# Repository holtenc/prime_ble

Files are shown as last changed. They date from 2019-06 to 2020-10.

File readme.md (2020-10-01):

This is a simple Bluetooth experiment I took on, just for grins. 

It utilizes an adafruit NRF51822 module and an Atmega32u4 MCU. Keyboard firmware is QMK

The portion of the schematic concerning the NRF module is based on the Adafruit Feather 32u4 Bluefruit LE schematic. 

A previous error in the PCB has been corrected by a contributor, but it has not been tested. 

These files are presented as-is for personal projects. They were created/uploaded in a time that I was ignorant of creating Kicad projects that were easily sharable so most likely you will get errors with schematic symbols and/or PCB footprints.

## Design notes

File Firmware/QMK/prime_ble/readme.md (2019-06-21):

# Prime_BLE

![Prime_BLE]()

An ergonomic bluetooth 45% keyboard with a macro/numpad added to the left side. 

Keyboard Maintainer: [Holtenc](https://github.com/holtenc/)  
Hardware Supported: Prime_ble PCB, ATMega32u4, NRF51822 
Hardware Availability: Prototype

Make example for this keyboard (after setting up your build environment):

    make handwired/prime_ble:default

See the [build environment setup](https://docs.qmk.fm/#/getting_started_build_tools) and the [make instructions](https://docs.qmk.fm/#/getting_started_make_guide) for more information. Brand new to QMK? Start with our [Complete Newbs Guide](https://docs.qmk.fm/#/newbs).

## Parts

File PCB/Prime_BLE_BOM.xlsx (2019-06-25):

Designator | Package | Quantity | Designation | Cost each | Total
D1 | IN-S124BR_LED | 1 |  | $0.30 | $0.30
D2 | IN-S124BR_LED | 1 |  | $0.30 | $0.30
CHG1 | IN-S124BR_LED | 1 |  | $0.30 | $0.30
D66,D67 | IN-S124BR_LED | 2 |  | $0.30 | $0.60
D3,D5,D6,D7,D8,D9,D10,D11,D12,D13,D14,D15,D16,D17,D18,D19,D20,D21,D22,D23,D24,D25,D26,D27,D28,D29,D30,D31,D32,D33,D34,D35,D36,D37,D38,D39,D40,D41,D42,D43,D44,D45,D46,D47,D48,D49,D50,D51,D52,D53,D54,D55,D56,D57,D58,D59,D60,D61,D62,D63,D64,D65 | D_SOD-123 | 62 |  | $0.10 | $6.20
SW4 | EG1213 | 1 | SW_SPDT | $0.65 | $0.65
C3 | 0603 | 1 | 470pF | $0.06 | $0.06
U4 | TQFP-44_10x10mm_P0.8mm | 1 | ATmega32U4-AU | $4.20 | $4.20
SW3,SW2,SW1 | TL3342F160 | 3 | SW_PUSH | $0.64 | $1.92
X2 | 2X05_1.27MM_BOX_POSTS | 1 | JTAG-CORTEXBOXPOSTS | $1.50 | $1.50
U1 | BLE_MODULE_RAYTAC_MDBT40 | 1 | MBT40 (adafruit 4076) | $7.50 | $7.50
X1 | JSTPH2 | 1 | S2B-PH-SM4-TB(LF)(SN) | $0.60 | $0.60
C1,C4 | 0603 | 2 | 22pF | $0.06 | $0.12
C5,C2 | 0603 | 2 | 1uF | $0.06 | $0.12
C7,C8,C12,C13 | 0603 | 4 | 0.1uF | $0.06 | $0.24
C9 | 0603 | 1 | 4.7uF | $0.06 | $0.06
C10,C11 | 1206 | 2 | 4.7uF | $0.20 | $0.40
F1 | PPTC_nano | 1 | 1206L050YR | $0.60 | $0.60
R3,R7,R9 | 0603 | 3 | 10k | $0.06 | $0.18
R4,R8 | 0603 | 2 | 5.1k | $0.06 | $0.12
R5,R6 | 0603 | 2 | 22 | $0.06 | $0.12
U2 | SOT-23-5 | 1 | MCP73831-2-OT | $0.60 | $0.60
U3 | SOT-23-5 | 1 | MIC5219-3.3YM5 | $1.00 | $1.00
USB1 | HRO-TYPE-C-31-M-12-HandSoldering | 1 | HRO-TYPE-C-31-M-12 | $0.50 | $0.50
Y1 | Crystal_SMD_Abracon_ABM3B-4Pin_5.0x3.2mm | 1 | 8MHz - 18pf | $1.00 | $1.00
R1,R10 | 0603 | 2 | 2.2K | $0.06 | $0.12
R2 | 0603 | 1 | 1K | $0.06 | $0.06
D4 | D_SMA_Handsoldering | 1 | B340AE-13 | $0.30 | $0.30
C14,C15 | 0603 | 2 | 10uF | $0.06 | $0.12
R11,R12 | 0603 | 2 | 1k | $0.06 | $0.12
 |  |  |  |  | 29.91

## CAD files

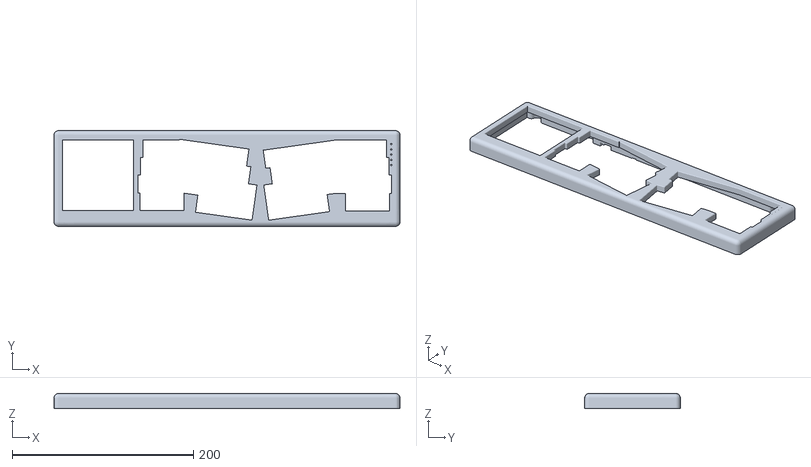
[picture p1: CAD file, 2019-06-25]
PCB/Prime_BLE/CAD/Prime_BLE_Top.stl
381.8 x 105.6 x 16.6

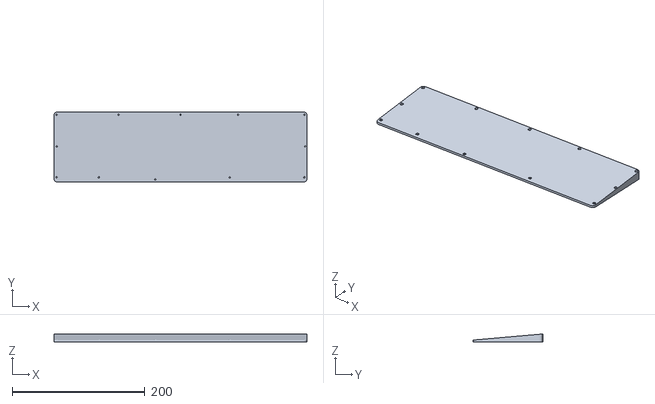
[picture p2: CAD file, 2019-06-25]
PCB/Prime_BLE/CAD/prime_ble_bottom.stl
381.8 x 105.6 x 12.2

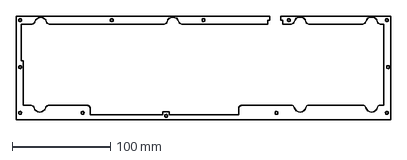
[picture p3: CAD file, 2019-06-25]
PCB/Prime_BLE/CAD/base_template.dxf
381.8 x 105.6 mm

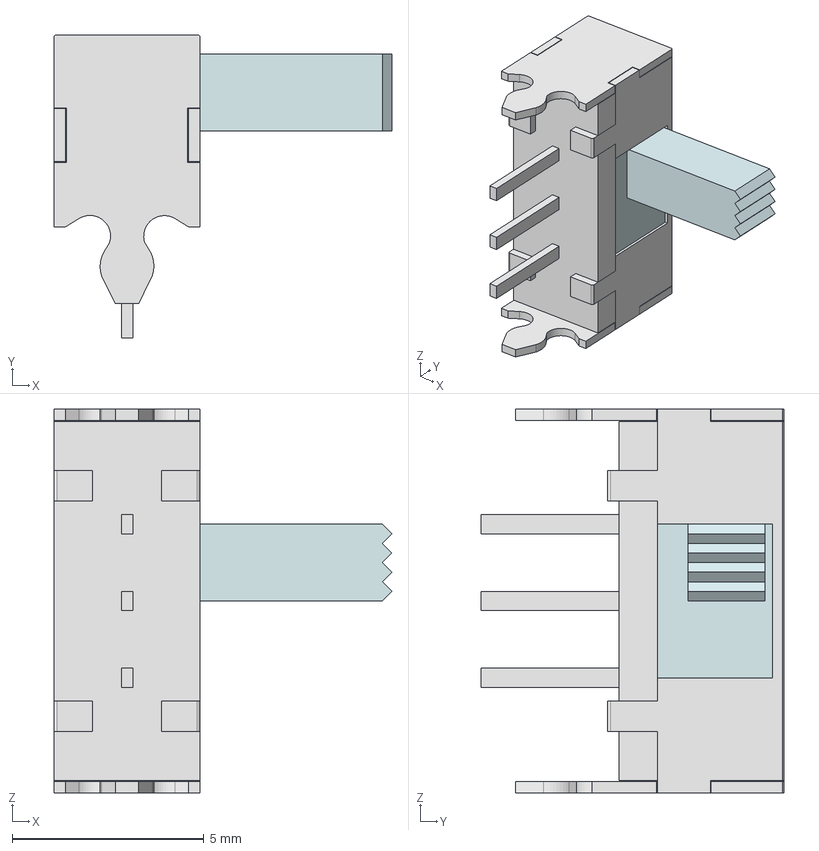
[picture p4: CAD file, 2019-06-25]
PCB/Prime_BLE/CAD/EG1213.stp
8.80 x 7.90 x 10.0 mm
EG1213 SHELL
EG1213 TERM
EG1213 ACTUATOR

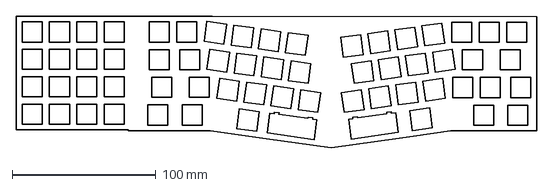
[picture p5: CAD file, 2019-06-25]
PCB/Prime_BLE/CAD/top template.dxf
362.2 x 91.6 mm

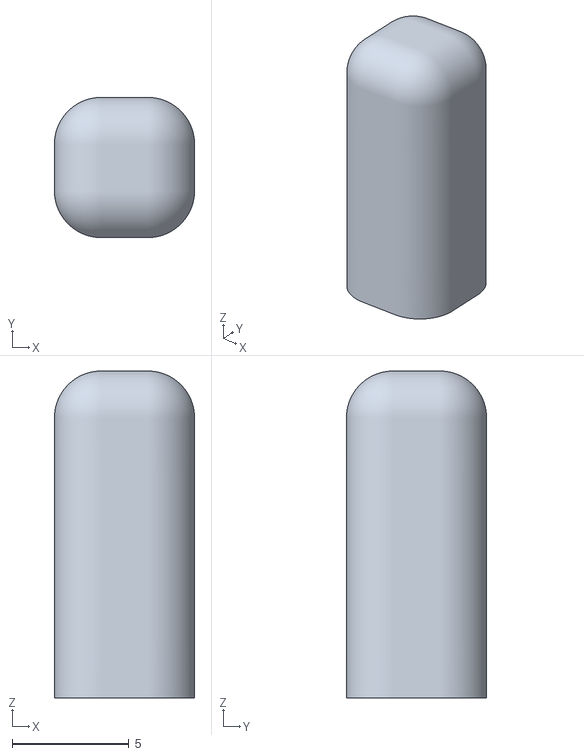
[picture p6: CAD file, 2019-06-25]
PCB/Prime_BLE/CAD/switch cover.stl
6.00 x 6.00 x 14.0

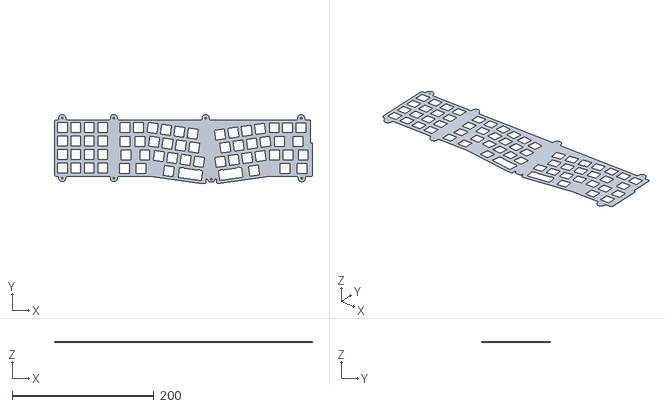
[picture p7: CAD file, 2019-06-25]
PCB/Prime_BLE/CAD/switch plate.stl
364.2 x 97.4 x 1.20

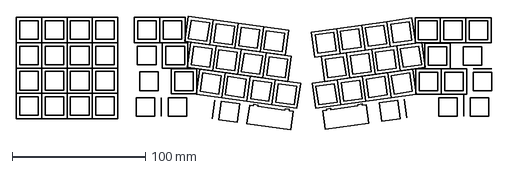
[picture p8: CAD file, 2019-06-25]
PCB/Prime_BLE/CAD/switch template.dxf
356.8 x 85.2 mm

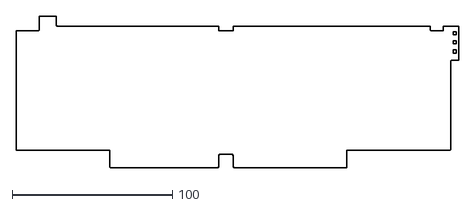
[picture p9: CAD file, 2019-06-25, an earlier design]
PCB/Prime_BLE/Old/Alice_40-Edge.Cuts.dxf
276.5 x 94.6

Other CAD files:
PCB/Prime_BLE/CAD/Assembly1.iam
PCB/Prime_BLE/CAD/COMPOUND.ipt
PCB/Prime_BLE/CAD/C_0603_1608Metric.iam
PCB/Prime_BLE/CAD/C_1206_3216Metric.iam
PCB/Prime_BLE/CAD/D_SMA.iam
PCB/Prime_BLE/CAD/D_SOD-123.iam
PCB/Prime_BLE/CAD/OldVersions/Assembly1.0007.iam
PCB/Prime_BLE/CAD/OldVersions/Prime_BLE_Top.0010.ipt
PCB/Prime_BLE/CAD/OldVersions/bottom.0009.ipt
PCB/Prime_BLE/CAD/OldVersions/switch cover.0004.ipt
PCB/Prime_BLE/CAD/OldVersions/switch plate.0010.ipt
PCB/Prime_BLE/CAD/OldVersions/switch template.0001.ipt
PCB/Prime_BLE/CAD/Prime_BLE_Top.ipt
PCB/Prime_BLE/CAD/R_0603_1608Metric.iam
PCB/Prime_BLE/CAD/SOLID.ipt
PCB/Prime_BLE/CAD/SOLID_1.ipt
PCB/Prime_BLE/CAD/SOLID_2.ipt
PCB/Prime_BLE/CAD/SOLID_3.ipt
PCB/Prime_BLE/CAD/SOLID_4.ipt
PCB/Prime_BLE/CAD/SOLID_5.ipt
PCB/Prime_BLE/CAD/SOLID_6.ipt
PCB/Prime_BLE/CAD/SOLID_7.ipt
PCB/Prime_BLE/CAD/SOT-23-5.iam
PCB/Prime_BLE/CAD/SW_SPST_TL3342.iam
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

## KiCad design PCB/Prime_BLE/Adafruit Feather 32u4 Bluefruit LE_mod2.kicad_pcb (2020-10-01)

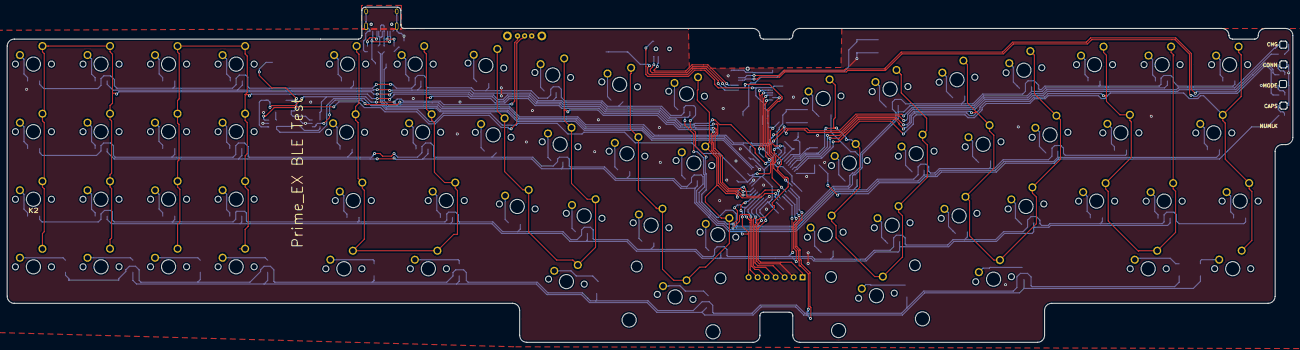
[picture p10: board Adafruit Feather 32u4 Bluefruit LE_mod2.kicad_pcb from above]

Board: 2 copper layers, 362.5 x 94.5 mm, 169 parts (0 on the bottom side), 115 nets.

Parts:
C1, C4: 22pF; C_0603_1608Metric_Pad1.05x0.95mm_HandSolder
C2, C5: 1uF; C_0603_1608Metric_Pad1.05x0.95mm_HandSolder
C3: 470pF; C_0603_1608Metric_Pad1.05x0.95mm_HandSolder
C7, C8, C12, C13: 0.1uF; C_0603_1608Metric_Pad1.05x0.95mm_HandSolder
C9: 4.7uF; C_0603_1608Metric_Pad1.05x0.95mm_HandSolder
C10, C11: 4.7uF; C_1206_3216Metric_Pad1.42x1.75mm_HandSolder
C14, C15: 10uF; C_0603_1608Metric_Pad1.05x0.95mm_HandSolder
D1, D2, D66, D67: LED; IN-S124BR_LED
D3, D5, D6, D7, D8, D9, D10, D11, D12, D13, D14, D15, D16, D17, D18, D19, D20, D21, D22, D23, D24, D25, D26, D27, D28, D29, D30, D31, D32, D33, D34, D35, D36, D37, D38, D39, D40, D41, D42, D43, D44, D45, D46, D47, D48, D49, D50, D51, D52, D53, D54, D55, D56, D57, D58, D59, D60, D61, D62, D63, D64, D65: D; D_SOD-123
D4: B340; D_SMA_Handsoldering
F1: PPTC; PPTC_nano
J1: JTAG_ITF; PinSocket_1x07_P2.54mm_Vertical
JP1: SolderJumper_2_Open; SolderJumper-2_P1.3mm_Open_RoundedPad1.0x1.5mm
K1, K2, K3, K4, K5, K6, K7, K8, K9, K10, K11, K12, K13, K17, K18, K19, K21, K22, K23, K24, K25, K26, K28, K29, K30, K31, K32, K33, K35, K36, K37, K39, K40, K41, K42, K43, K44, K46, K47, K48, K49, K50, K51, K52, K53: KEYSW; CHERRY_PCB_100H
K14, K16, K20, K27, K45, K54, K56, K57: KEYSW; CHERRY_PCB_125H
K15, K55: KEYSW; CHERRY_PCB_175H
K34: KEYSW; CHERRY_PCB_200H
K38: KEYSW; CHERRY_PCB_225H
K?1, K?2, K?3, K?4, K?5: KEYSW; CHERRY_PCB_100H
R1, R2, R11: 2.2k; R_0603_1608Metric
R3, R7, R9: 10k; R_0603_1608Metric
R4, R8: 5.1k; R_0603_1608Metric
R5, R6: 22; R_0603_1608Metric
R10: 2.2K; R_0603_1608Metric
SW1, SW2, SW3: SW_PUSH; SW_TACTILE_SMD
SW4: SW_SPDT; SW_EG1212
U1: MBT40; BLE_MODULE_RAYTAC_MDBT40
U2: MCP73831-2-OT; SOT-23-5
U3: MIC5219-3.3YM5; SOT-23-5
U4: ATmega32U4-AU; TQFP-44_10x10mm_P0.8mm
USB1: HRO-TYPE-C-31-M-12; HRO-TYPE-C-31-M-12-HandSoldering
X1: JSTPH; JSTPH2
X2: JTAG-CORTEXBOXPOSTS; 2X05_1.27MM_BOX_POSTS
Y1: 8MHz; Crystal_SMD_Abracon_ABM3B-4Pin_5.0x3.2mm

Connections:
+3V3: C2.1, C5.1, C7.1, C8.1, C9.1, C12.1, C13.1, C14.1, C15.1, J1.1, R3.1, U1.3, U1.14, U3.5, U4.6, U4.14, U4.24, U4.34, U4.42, U4.44, X2.1
+BATT: C11.1, D4.2, U2.3, X1.2
/BLE_CS: U1.7, U4.28
/BLE_IRQ: U1.8, U4.1
/CAPS: JP1.1, U4.22
/CONNECTED: R10.1, U1.39
/Col0: K1.1, K2.1, K3.1, K4.1, K5.1, K6.1, K?1.1, K?2.1, U4.12
/Col1: K7.1, K8.1, K9.1, K10.1, K11.1, K12.1, K?3.1, K?4.1, U4.41
/Col2: K13.1, K14.1, K15.1, K16.1, K17.1, K18.1, K19.1, K20.1, U4.40
/Col3: K21.1, K22.1, K23.1, K24.1, K25.1, K26.1, K27.1, U4.32
/Col4: K28.1, K29.1, K30.1, K31.1, K32.1, K33.1, K34.1, U4.31
/Col5: K35.1, K36.1, K37.1, K38.1, K39.1, K40.1, K41.1, U4.18
/Col6: K42.1, K43.1, K44.1, K45.1, K46.1, K47.1, K48.1, U4.19
/Col7: K49.1, K50.1, K51.1, K52.1, K53.1, K54.1, U4.20
/Col8: K55.1, K56.1, K57.1, K?5.1, U4.21
/D+: R6.2, U4.4
/D-: R5.2, U4.3
/FCTRYRST: SW3.2, U1.34
/MISO: U1.5, U4.11
/MODE: R1.1, U1.38
/MOSI: U1.6, U4.10
/RST: J1.3, R3.2, SW1.2, U4.13
/Row0: D7.1, D15.1, D23.1, D34.1, D45.1, D61.1, U4.27
/Row1: D6.1, D14.1, D22.1, D30.1, D37.1, D44.1, D51.1, D58.1, D64.1, U4.30
/Row2: D5.1, D13.1, D21.1, D29.1, D36.1, D43.1, D50.1, D57.1, J1.5, U4.37
/Row3: D3.1, D12.1, D20.1, D28.1, D35.1, D42.1, D49.1, D56.1, D62.1, J1.4, U4.36
/Row4: D8.1, D16.1, D24.1, D31.1, D38.1, D46.1, D53.1, D59.1, J1.6, U4.38
/Row5: D9.1, D17.1, D25.1, D32.1, D39.1, D47.1, D54.1, D63.1, J1.7, U4.39
/Row6: D10.1, D18.1, D26.1, D33.1, D40.1, D48.1, D55.1, D60.1, U4.29
/Row7: D11.1, D19.1, D27.1, D41.1, D52.1, D65.1, U4.26
/SCK: U1.4, U4.9
/SWCLK: U1.36, X2.4
/SWDIO_RST: U1.35, U4.25, X2.2
GND: C1.2, C2.2, C3.1, C4.2, C5.2, C7.2, C8.2, C9.2, C10.2, C11.2, C12.2, C13.2, C14.2, C15.2, D1.1, D2.1, D66.1, J1.2, R4.2, R7.2, R8.2, R9.2, SW1.1, SW2.1, SW3.1, SW4.3, U1.1, U1.2, U1.13, U1.16, U1.25, U1.42, U2.2, U3.2, U4.5, U4.15, U4.23, U4.35, U4.43, USB1.1, USB1.12, USB1.13, X1.1, X2.3, X2.5, X2.7, X2.9, Y1.2, Y1.4
unnamed: C1.1, U4.17, Y1.1
unnamed: C3.2, U3.4
unnamed: C4.1, U4.16, Y1.3
unnamed: D1.2, R1.2
unnamed: D2.2, R10.2
unnamed: D3.2, K?1.2
unnamed: D5.2, K1.2
unnamed: D6.2, K2.2
unnamed: D7.2, K3.2
unnamed: D8.2, K?2.2
unnamed: D9.2, K4.2
unnamed: D10.2, K5.2
unnamed: D11.2, K6.2
unnamed: D12.2, K?3.2
unnamed: D13.2, K7.2
unnamed: D14.2, K8.2
unnamed: D15.2, K9.2
unnamed: D16.2, K?4.2
unnamed: D17.2, K10.2
unnamed: D18.2, K11.2
unnamed: D19.2, K12.2
unnamed: D20.2, K13.2
unnamed: D21.2, K14.2
unnamed: D22.2, K15.2
unnamed: D23.2, K16.2
unnamed: D24.2, K17.2
unnamed: D25.2, K18.2
unnamed: D26.2, K19.2
unnamed: D27.2, K20.2
unnamed: D28.2, K21.2
unnamed: D29.2, K22.2
unnamed: D30.2, K23.2
unnamed: D31.2, K24.2
unnamed: D32.2, K25.2
unnamed: D33.2, K26.2
unnamed: D34.2, K27.2
unnamed: D35.2, K28.2
unnamed: D36.2, K29.2
unnamed: D37.2, K30.2
unnamed: D38.2, K31.2
unnamed: D39.2, K32.2
unnamed: D40.2, K33.2
unnamed: D41.2, K34.2
unnamed: D42.2, K35.2
unnamed: D43.2, K36.2
unnamed: D44.2, K37.2
unnamed: D45.2, K38.2
unnamed: D46.2, K39.2
unnamed: D47.2, K40.2
unnamed: D48.2, K41.2
unnamed: D49.2, K42.2
unnamed: D50.2, K43.2
unnamed: D51.2, K44.2
unnamed: D52.2, K45.2
unnamed: D53.2, K46.2
unnamed: D54.2, K47.2
unnamed: D55.2, K48.2
unnamed: D56.2, K49.2
unnamed: D57.2, K50.2
unnamed: D58.2, K51.2
unnamed: D59.2, K52.2
unnamed: D60.2, K53.2
unnamed: D61.2, K54.2
unnamed: D62.2, K?5.2
unnamed: D63.2, K55.2
unnamed: D64.2, K56.2
unnamed: D65.2, K57.2
unnamed: D66.2, R11.2
unnamed: D67.1, R2.1
unnamed: F1.1, USB1.2, USB1.11
unnamed: JP1.2, R11.1
unnamed: R2.2, U2.1
unnamed: R4.1, USB1.4
unnamed: R5.1, USB1.5, USB1.7
unnamed: R6.1, USB1.6, USB1.8
unnamed: R7.1, U2.5
unnamed: R8.1, USB1.10
unnamed: R9.1, U4.33
unnamed: SW2.2, U1.24
unnamed: SW4.2, U3.3
VBUS: C10.1, D4.1, D67.2, F1.2, SW4.1, U2.4, U3.1, U4.7

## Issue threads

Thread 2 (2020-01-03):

use kicad open .sch get the error, need libraries.

YeungKC, 2020-01-03:
Is it possible to provide these libraries?
https://github.com/holtenc/prime_ble/blob/b8d139801db2097f71a4e3d8e7354d306192ecab/PCB/Prime_BLE/sym-lib-table
plz

mitchsw, 2020-07-24:
Hi, I would also be interested in this! Thank you

Closed 2020-10-01.

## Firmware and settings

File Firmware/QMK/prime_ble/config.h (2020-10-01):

/*
Copyright 2018 Holten Campbell

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
You should have received a copy of the GNU General Public License
along with this program.  If not, see <http://www.gnu.org/licenses/>.
*/

#pragma once

#include "config_common.h"

/* USB Device descriptor parameter */
#define VENDOR_ID       0x5052
#define PRODUCT_ID      0x6580
#define DEVICE_VER      0x0001
#define MANUFACTURER    PrimeKB
#define PRODUCT         Prime_BLE
#define DESCRIPTION     Ergo

/* key matrix size */
#define MATRIX_ROWS 8
#define MATRIX_COLS 9

/* Keyboard Matrix Assignments */
#define MATRIX_ROW_PINS { D7, B6, F6, F7, F5, F4, B5, D6 }
#define MATRIX_COL_PINS { B7, F0, F1, C7, C6, D0, D1, D2, D3 }
#define UNUSED_PINS

/* COL2ROW, ROW2COL*/
#define DIODE_DIRECTION COL2ROW


//#define BACKLIGHT_PIN B7
//define BACKLIGHT_LEVELS 5


/*Bluetooth */
#define AdafruitBleResetPin D4
#define AdafruitBleCSPin B4
#define AdafruitBlEIRQPin E6

/* Debounce reduces chatter (unintended double-presses) - set 0 if debouncing is not needed */
#define DEBOUNCING_DELAY 5

/* Mechanical locking support. Use KC_LCAP, KC_LNUM or KC_LSCR instead in keymap */
#define LOCKING_SUPPORT_ENABLE
/* Locking resynchronize hack */
#define LOCKING_RESYNC_ENABLE

#define DYNAMIC_KEYMAP_LAYER_COUNT 4

// EEPROM usage

// TODO: refactor with new user EEPROM code (coming soon)
#define EEPROM_MAGIC 0x451F
#define EEPROM_MAGIC_ADDR 32
// Bump this every time we change what we store
// This will automatically reset the EEPROM with defaults
// and avoid loading invalid data from the EEPROM
#define EEPROM_VERSION 0x08
#define EEPROM_VERSION_ADDR 34

// Dynamic keymap starts after EEPROM version
#define DYNAMIC_KEYMAP_EEPROM_ADDR 35
// Dynamic macro starts after dynamic keymaps (35+(4*8*9*2)) = (35+576)
#define DYNAMIC_KEYMAP_MACRO_EEPROM_ADDR 611
#define DYNAMIC_KEYMAP_MACRO_EEPROM_SIZE 413    // 1024-DYNAMIC_KEYMAP_MACRO_EEPROM_ADDR
#define DYNAMIC_KEYMAP_MACRO_COUNT 16

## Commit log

2019-06-25 re-arrange and update files
    [Adafruit Feather 32u4 Bluefruit LE.kicad_pcb, Adafruit Feather 32u4 Bluefruit LE.sch, Adafruit Feather 32u4 Bluefruit LE_mod.kicad_pcb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]
2019-06-25 add BOM
    [Prime_BLE_BOM.xlsx]
2020-09-30 fixed issues detailed in the master branch readme
    [Adafruit Feather 32u4 Bluefruit LE_mod2.kicad_pcb]
2020-09-30 modify matrix pins
    modified matrix pins to match the issues corrected
    [config.h]

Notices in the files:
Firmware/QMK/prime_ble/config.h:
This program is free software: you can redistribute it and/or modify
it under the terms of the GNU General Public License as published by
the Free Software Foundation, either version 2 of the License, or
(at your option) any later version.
